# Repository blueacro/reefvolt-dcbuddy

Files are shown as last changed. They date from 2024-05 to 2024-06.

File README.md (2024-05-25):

# blueAcro ReefVolt DCBuddy

> Tired of AC bricks? Try the DCBuddy!

Various DC power accessories for the aquarium market

## DCBuddy

An Open Hardware design for 12-36V aquarium accessories, featuring:

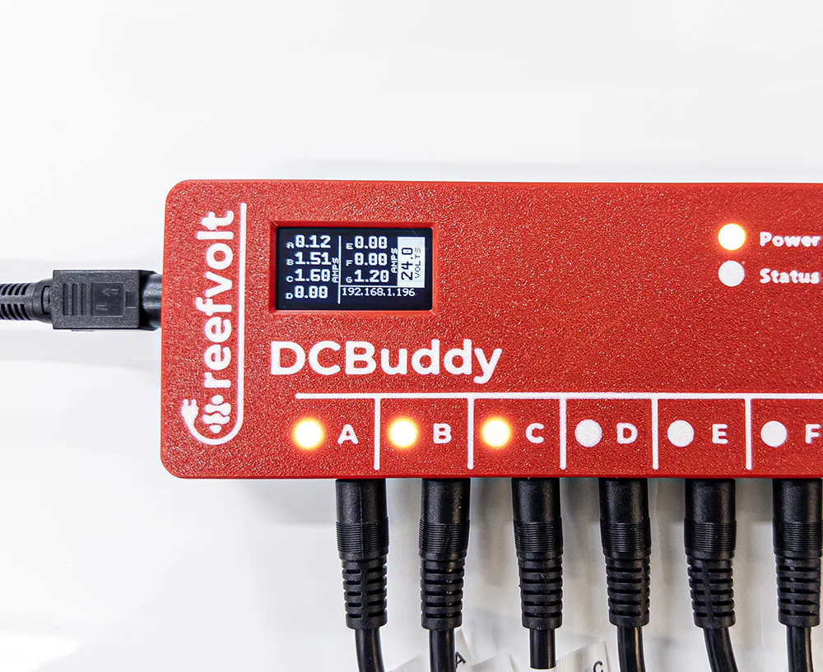
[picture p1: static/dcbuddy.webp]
Finished hardward

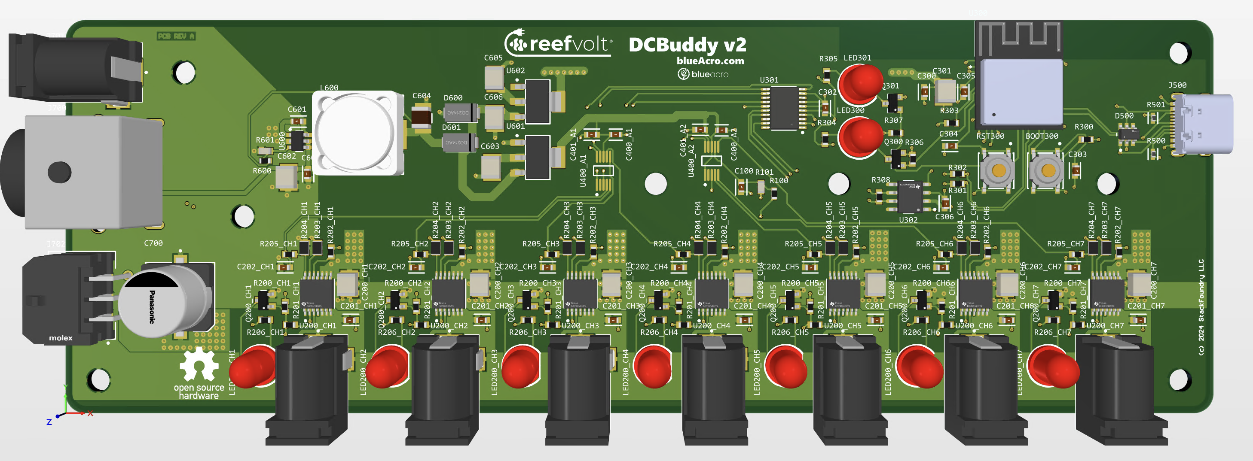
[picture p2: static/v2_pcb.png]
PCB screenshot


1. 7x, up to 5A (3A sustained), switched and current monitored power
   outlets with short circuit protection.
2. Works on an input range of 12-36V, up to 10A total current.
3. ESP32 on board, with USB-C port, for integration in Home Assistant.
4. Multiple input connectors including 2.1x5.5mm jack, DIN-4 jack, and
   Micro-Fit 3.0 jack with CAN bus support for power modules

## Buy

This product is available to purchase on https://blueacro.com

## Docs

More documentation is available on https://reefvolt.com/

## Firmware Install (Recovery, USB-C)

Need to reinstall the latest firmware? Visit
https://blueacro.github.io/reefvolt-dcbuddy/ with a Chrome-based
browser, plug in the DCBuddy over USB, and click Connect.

### Design Thread

This project was started on Reef2Reef. See the thread:

https://www.reef2reef.com/threads/tired-of-ac-bricks-try-the-dcbuddy.1009642/

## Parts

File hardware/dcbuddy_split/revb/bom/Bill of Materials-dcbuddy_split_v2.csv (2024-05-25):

Comment | Description | Designator | Footprint | LibRef | Quantity
PTS526SK15SMTR2LFS | Switch Tactile N.O. SPST Round Button Gull Wing 0.05A 12VDC 200000Cycles 2.45N SMD T/R | BOOT300, RST300, USR300 | FP-PTS526SK15SMTR2LFS-MFG | CMP-011-00015-1 | 3
CAP 1uF 10V X7R 0603 | Cap Ceramic 1uF 10V X7R 10% SMD 0603 125C Paper T/R | C100, C302, C304 | FP-CL10-IPC_B | CMP-001-00085-7 | 3
CAP 4.7uF 50V X7R 1210 | CAP CER 4.7UF 50V X7R 1210 | C200_A, C200_B, C200_C, C200_D, C200_E, C200_F, C200_G, C301, C605, C606 | CAPC3225X20N | CMP-001-00083-3 | 10
CAP 0.1uF 50V X7R 0603 | Cap Ceramic 0.1uF 50V X7R 20% SMD 0603 125C Paper T/R | C201_A, C201_B, C201_C, C201_D, C201_E, C201_F, C201_G, C202_A, C202_B, C202_C, C202_D, C202_E, C202_F, C202_G, C300, C303, C305, C306, C307, C401_X, C401_Y, C611 | FP-CL10-IPC_B | CMP-001-00084-7 | 22
CAP 4.7uF 0603 6.3V X7R | Cap Ceramic 4.7uF 6.3V X7R 10% SMD 0603 125°C Paper T/R | C400_X, C400_Y, C603, C613, C614 | FP-CL10-IPC_C | CMP-001-00101-4 | 5
CAP 2.2uF 0603 16V X6S | Cap Ceramic 2.2uF 16V X6S 10% Pad SMD 0603 105°C Low ESR T/R | C600 | FP-C1608-080-0_1-IPC_A | CMP-001-00117-2 | 1
CAP 0.47uF 50V 0603 | Multilayer Ceramic Capacitor, 0.47 uF, 50 V, ± 10%, X7R, 0603 [1608 Metric] | C601 | FP-C1608-080-0_1-IPC_A | CMP-001-00116-2 | 1
CAP 0.47uF 1210 50V X7R | Multilayer Ceramic Capacitor, 0.47 uF, 50 V, ± 10%, X7R, 1210 [3225 Metric] | C602, C609 | CAPC1210(3225)230_M | CMP-001-00128-1 | 2
CAP 10uF 1210 63V X7R | Multilayer Ceramic Capacitors MLCC - SMD/SMT 1210 10uF 63volts *Derate Voltage/Temp | C604, C610 | FP-GRM32E-0_2-0_3-MFG | CMP-001-00119-1 | 2
CAP 22uF 25V 1210 X7R | 1210 22 uF 25 V ±20% Tolerance X7R Multilayer Ceramic Chip Capacitor | C607 | FP-1210-L_3_2_0_3-W_2_5_0-MFG | CMP-001-00125-1 | 1
CAP 120uF 35V Poly 10mm | Cap Aluminum Polymer 120uF 35VDC 20%( 10 X 12.6mm) SMD 0.018 Ohm 4400mA 5000h 105C T/R | C608 | FP-OS-CON-SMT-F12-MFG | CMP-001-00127-1 | 1
C0603C560J5GACTU | Multilayer Ceramic Capacitor, 56 pF, 50 V, ± 5%, C0G (NP0), 0603 [1608 Metric] | C612 | FP-C0603C-CF-IPC_B | CMP-001-00126-1 | 1
CAP 56uF 63V Poly 10mm | Cap Aluminum 56uF 63V 20% (10 X 10.2mm) SMD 0.03 Ohm 1800mA 5000h 105 C Embossed T/R | C700 | FP-FKG-MFG | CMP-001-00124-1 | 1
USBLC6-4SC6 | ESD Suppressor 15KV 6-Pin SOT-23 T/R - Product that comes on tape, but is not reeled | D500 | FP-SOT23-6L-MFG | CMP-004-00040-1 | 1
SS14 |  | D600, D601 | SMA | CMP-080-0002-2 | 2
OLED_1_3_CARRIERBOARD | Use 4 pin header 0901471104 on board | DISP800 | OLED_1_3_CARRIERBOARD-Footprint-1 | CMP-00028-00008-2 | 1
PJ-0XX | 2.0 x 6.5 mm, 2.5 A, Horizontal, Through Hole, Dc Power Jack Connector | J200_A, J200_B, J200_C, J200_D, J200_E, J200_F, J200_G, J701 | CUI-PJ-002A_V | CMP-167-0003-2 | 8
M50-3630342R | 3 Pos. Male SIL Vertical SMT Conn. RoHS Compliant: Yes | J300, J600 | FP-M50-3630342R-MFG | CMP-002-00105-2 | 2
10155435-00011LF | 16 Position 5 A USB Right Angle Receptacle Connector | J500 | AMPHENOL_10155435-00011LF | CMP-243-000000-3 | 1
DIN4PWR |  | J700 | PD40S | CMP-167-0005-1 | 1
43045-1001 | Connector Wire to Board Header 10 Position 3 mm Solder Right Angle Thru-Hole Micro-Fit 3.0™ | J702 | FP-43045-1001-MFG | CMP-002-00106-1 | 1
IHLP5050FDER100M01 | Inductor Power Shielded Wirewound 10uH 20% 100KHz Powdered Iron 10A 17.2mOhm DCR 5050 T/R | L600 | FP-IHLP-5050FD-FP_2_945x4-MFG | CMP-006-00033-1 | 1
SRN4018-4R7M | Ind Power Semi-Shielded Wirewound 4.7uH 20% 100KHz Ferrite 1.9A 1515 T/R | L601 | FP-SRN4018-MFG | CMP-006-00036-2 | 1
LED_INDICATOR |  | LED200_A, LED200_B, LED200_C, LED200_D, LED200_E, LED200_F, LED200_G, LED300, LED301 | LED5MM | CMP-130-0003-6 | 9
NFET |  | Q200_A, Q200_B, Q200_C, Q200_D, Q200_E, Q200_F, Q200_G, Q300, Q301 | SOT23-3 | CMP-094-0000-1 | 9
100k 0603 1% | SMD Chip Resistor, 100 kOhm, ± 1%, 100 mW, 0603 [1608 Metric], Thick Film, General Purpose, Res Thick Film 1.6 x 0.8 mm 100K Ohm 1% 0.1W(1/10W) 100ppm/ C Molded SMD Paper T/R | R100, R600, R604 | RESC1608-IPC-LL | CMP-009-00222-1, CMP-009-00203-1 | 3
12k 0603 1% | SMD Chip Resistor, 12 kOhm, ± 1%, 100 mW, 0603 [1608 Metric], Thick Film, General Purpose | R101 | RESC1608X55X25LL10T15 | CMP-009-00236-1 | 1
10K 0603 1% | Res General Purpose Thick Film 0603 10K Ohm 1% 1/10W ±100ppm/°C Molded SMD Paper T/R | R200_A, R200_B, R200_C, R200_D, R200_E, R200_F, R200_G, R300, R301, R302, R303, R306, R307, R310 | RESC1608-IPC-ML | CMP-009-00191-4 | 14
4.7k 0603 1% | RES SMD 4.7K OHM 1% 1/10W 0603 | R201_A, R201_B, R201_C, R201_D, R201_E, R201_F, R201_G, R202_A, R202_B, R202_C, R202_D, R202_E, R202_F, R202_G, R205_A, R205_B, R205_C, R205_D, R205_E, R205_F, R205_G | RESC1608-IPC-ML | CMP-009-00205-1 | 21
RC0805FR-07470RL | SMD Chip Resistor, 470 Ohm, ± 1%, 125 mW, 0805 [2012 Metric], Thick Film, General Purpose | R203_A, R203_B, R203_C, R203_D, R203_E, R203_F, R203_G, R204_A, R204_B, R204_C, R204_D, R204_E, R204_F, R204_G | RESC2013X60X35LL10T20 | CMP-009-00233-1 | 14
220R 0603 5% | YAGEO - RC0603JR-07220RL - SMD Chip Resistor, 0603 [1608 Metric], 220 ohm, RC Series, 75 V, Thick Film, 100 mW | R206_A, R206_B, R206_C, R206_D, R206_E, R206_F, R206_G, R304, R305 | RESC1608-IPC-ML | CMP-009-00183-3 | 9
120R 1210 5% | SMD Chip Resistor, 120 Ohm, ± 5%, 500 mW, 1210 [3225 Metric], Thick Film, General Purpose | R308 | RESC3225X70X50LL20T20 | CMP-009-00240-1 | 1
AC0402FR-075K1L | SMD Chip Resistor, 5.1 kOhm, ± 1%, 63 mW, 0402 [1005 Metric], Thick Film, General Purpose | R500, R501 | FP-AC0402-IPC_A | CMP-009-00234-1 | 2
97.6k 0603 1% | Res Thick Film 0603 97.6K Ohm 1% 1/10W ±100ppm/°C Molded SMD Paper T/R | R602 | RESC1608-IPC-LL | CMP-009-00223-1 | 1
9.09k 0603 1% | SMD Chip Resistor, 9.09 kOhm, ± 1%, 100 mW, 0603 [1608 Metric], Thick Film, General Purpose | R603 | RESC1608-IPC-LL | CMP-009-00221-1 | 1
22.1k 0603 0.1% | RES SMD 22.1KOHM 0.1% 1/10W 0603 | R605 | RESC1608-IPC-LL | CMP-009-00207-3 | 1
4.32k 0603 1% | SMD Chip Resistor, 4.32 kOhm, ± 1%, 100 mW, 0603 [1608 Metric], Thick Film, Precision | R606 | RESC1608X55X30LL15T15 | CMP-009-00239-1 | 1
TPS1H100BQPWPRQ1 | Current Limit SW 1-IN 1-OUT 5V to 40V 4A Automotive 14-Pin HTSSOP EP T/R | U200_A, U200_B, U200_C, U200_D, U200_E, U200_F, U200_G | FP-PWP0014C-IPC_C | CMP-024-00009-1 | 7
ESP32-C3-MINI-1-N4 | Bluetooth, WiFi 802.11b/g/n, Bluetooth v5.0 Transceiver Module 2.412GHz ~ 2.484GHz PCB Trace Surface Mount | U300 | XCVR_ESP32-C3-MINI-1-N4 | CMP-206-000000-1 | 1
PCA9554APW | I2C/SMBus Interface 100kHz/400kHz 5.5V 16-Pin TSSOP Tube / IC I/O EXPANDER I2C 8B 16TSSOP | U301 | PW0016A_L | CMP-015-00016-1 | 1
TCAN1044VDRQ1 | R-PDSO-G8 TCAN1044 Tape & Reel (TR) CAN interface transceiver 100mV 4.905mm 5Mbps -40C~125C TA | U302 | FP-D0008A-IPC_B | CMP-015-00017-1 | 1
ADS1115IDGSR | 4-Channel Single ADC Delta-Sigma 860sps 16-bit Serial 10-Pin VSSOP T/R | U400_X, U400_Y | FP-DGS0010A-MFG | CMP-015-00014-1 | 2
LM76005RNPR | 3.5-V to 60-V, 5-A synchronous step-down voltage converter 30-WQFN -40 to 125 | U600 | FP-RNP0030A-MFG | CMP-019-00072-2 | 1
TPS70950DBVT | IC REG LINEAR 5V 150MA SOT23-5 / 150-mA, 30-V, UltraLow IQ, Low-Dropout Regulators with Enable | U601, U603 | FP-DBV0005A-IPC_B | CMP-019-00083-1 | 2
TPS54202DDCR | 4.5V to 28V Input, 2A Output, EMI Friendly Synchronous Step-Down Converter 6-SOT-23-THIN -40 to 125 | U602 | FP-DDC0006A-IPC_C | CMP-019-00081-1 | 1

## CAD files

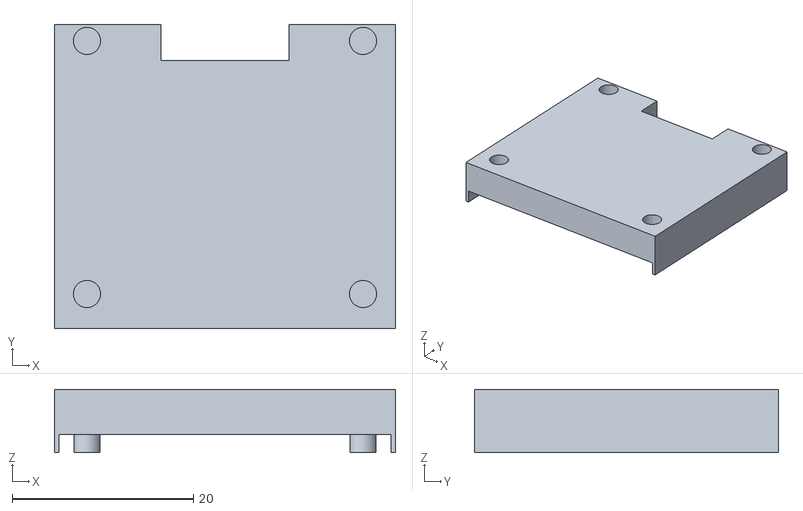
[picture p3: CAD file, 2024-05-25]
hardware/dcbuddy/case/reva/OledCarrier.stl
37.7 x 33.6 x 7.00

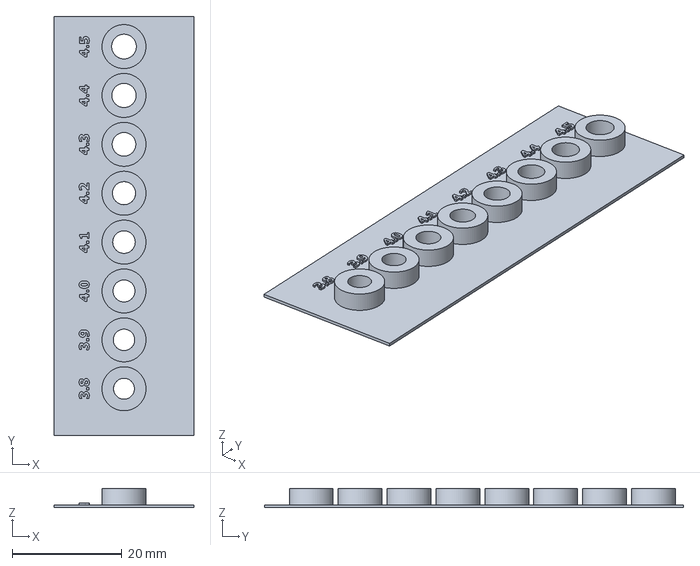
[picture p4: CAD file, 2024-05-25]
hardware/dcbuddy/case/reva/PCB/test plate press insert.3mf
25.4 x 76.2 x 3.50 mm

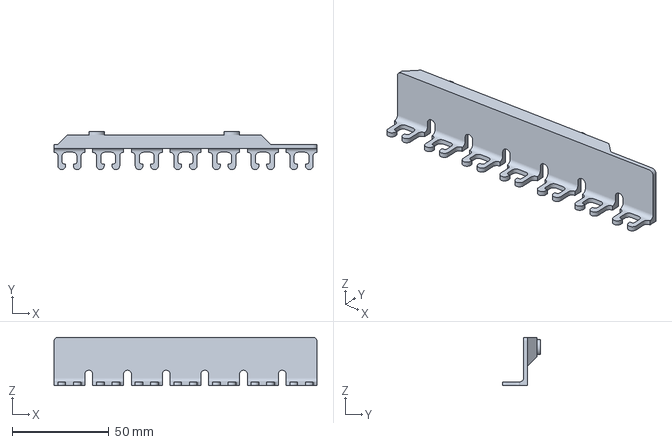
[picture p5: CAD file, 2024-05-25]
hardware/dcbuddy/case/reva/PCB/DCB2_CableClip.3mf
136.0 x 19.8 x 25.0 mm

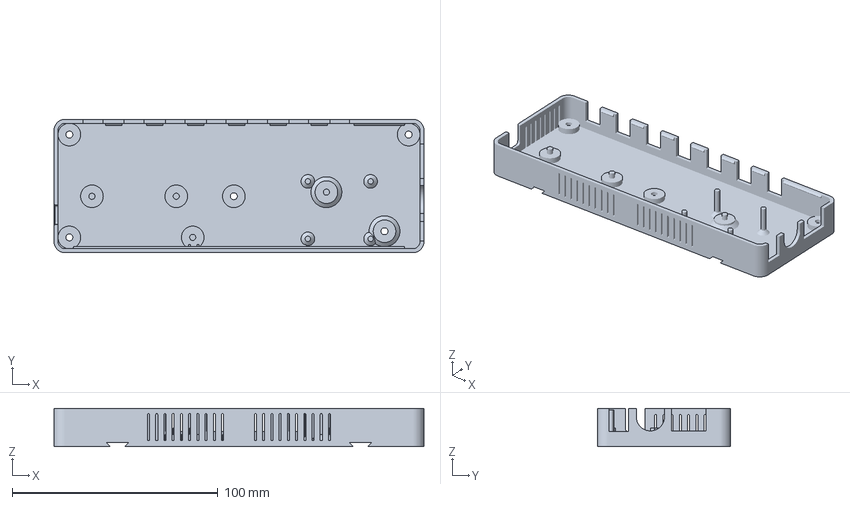
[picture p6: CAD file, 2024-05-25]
hardware/dcbuddy/case/reva/PCB/DCB2_BottomShell.3mf
179.9 x 64.9 x 18.6 mm

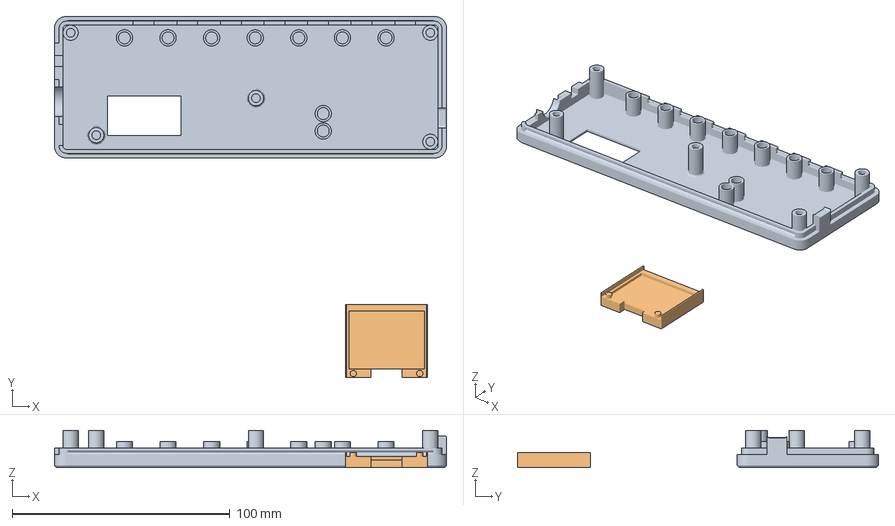
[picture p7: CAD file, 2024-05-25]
hardware/dcbuddy/case/reva/PCB/DCB2_TopShell.3mf
179.9 x 165.6 x 17.1 mm
DCB2_TopShell.stl
OledCarrier.stl

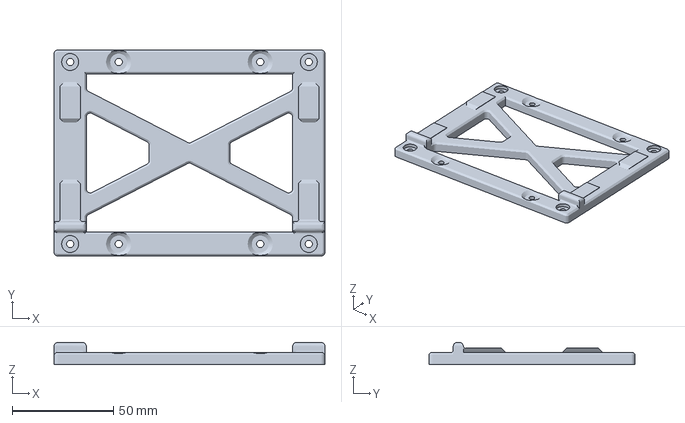
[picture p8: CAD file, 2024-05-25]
hardware/dcbuddy/case/reva/PCB/DCB2_Flange.3mf
134.0 x 102.0 x 11.0 mm

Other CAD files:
hardware/dcbuddy/case/reva/901471104.ipt
hardware/dcbuddy/case/reva/OLED_With_Carrier.iam
hardware/dcbuddy/case/reva/OledCarrier.ipt
hardware/dcbuddy/case/reva/PCB/ConvertedComponents/AMPHENOL_10155435-00011LF_CMP-243-000000-3.ipt
hardware/dcbuddy/case/reva/PCB/ConvertedComponents/CAPC3225X20N_CMP-001-00083-3.ipt
hardware/dcbuddy/case/reva/PCB/ConvertedComponents/CUI-PJ-002A_V_CMP-167-0003-2.ipt
hardware/dcbuddy/case/reva/PCB/ConvertedComponents/DCY0004A_M_CMP-019-00078-1.ipt
hardware/dcbuddy/case/reva/PCB/ConvertedComponents/DCY0004A_M_CMP-019-00080-1.ipt
hardware/dcbuddy/case/reva/PCB/ConvertedComponents/FP-1210-L_3_2_0_3-W_2_5_0-MFG_CMP-001-00125-1.ipt
hardware/dcbuddy/case/reva/PCB/ConvertedComponents/FP-43045-0601-MFG_CMP-002-00095-1.ipt
hardware/dcbuddy/case/reva/PCB/ConvertedComponents/FP-43045-0802-MFG_CMP-002-00102-1.ipt
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

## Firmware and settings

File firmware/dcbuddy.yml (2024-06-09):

esphome:
  name: dcbuddy
  comment: "Aquarium port controller"
  project:
    name: reefvolt.dcbuddy
    version: "v2"
  name_add_mac_suffix: true
  platformio_options:
    board_build.flash_mode: dio
  friendly_name: DCBuddy
  on_boot:
    priority: 600
    then:
      - output.turn_on: power_led

dashboard_import:
  package_import_url: github://blueacro/reefvolt-dcbuddy/firmware/dcbuddy.yaml@main
  import_full_config: false # or true

network:
    enable_ipv6: true

esp32:
  board: esp32-c3-devkitm-1
  framework:
    type: arduino

# Enable logging
logger:
  logs:
    component: ERROR # Suppress warning logs from the display drawing for too long

# Enable Home Assistant API
api:
  reboot_timeout: 0s # Prevent rebooting if no HA is connected
  services:
    - service: reset_ocp # Service to reset all OCP states
      then:
        - lambda: |-
            id(power_resets_port)[0] = 0;
            id(power_resets_port)[1] = 0;
            id(power_resets_port)[2] = 0;
            id(power_resets_port)[3] = 0;
            id(power_resets_port)[4] = 0;
            id(power_resets_port)[5] = 0;
            id(power_resets_port)[6] = 0;

ota:

wifi:
  # Enable fallback hotspot (captive portal) in case wifi connection fails
  ap:
    ssid: "DCBuddy Fallback Hotspot"
    password: "password"

prometheus:

web_server:
  port: 80
  log: False
  version: 3

improv_serial:

captive_portal:

status_led:
  pin: GPIO3

font:
    - file: 'five.ttf'
      id: five
      size: 8
    - file: "refsan.ttf"
      id: refsan
      size: 9
    - file: "PixelGameFont.ttf"
      id: bigfont
      size: 14


display:
  - platform: ssd1306_i2c
    model: "SH1106 128x64"
    #address: 0x78
    update_interval: 1s
    lambda: |-

     int offset = 0;
     it.printf(0, 3+offset, id(five), "A");
     it.printf(8, offset, id(bigfont), "%1.2f", fabs(id(amps_A).state));

     it.printf(55, 3+offset, id(five), "E");
     it.printf(55+8, offset, id(bigfont), "%1.2f", fabs(id(amps_E).state));

     offset += 16;

     it.printf(0, 3+offset, id(five), "B");
     it.printf(8, offset, id(bigfont), "%1.2f", fabs(id(amps_B).state));

     it.printf(55, 3+offset, id(five), "F");
     it.printf(55+8, offset, id(bigfont), "%1.2f", fabs(id(amps_F).state));

     offset += 16;

     it.printf(0, 3+offset, id(five), "C");
     it.printf(8, offset, id(bigfont), "%1.2f", fabs(id(amps_C).state));

     it.printf(55, 3+offset, id(five), "G");
     it.printf(55+8, offset, id(bigfont), "%1.2f", fabs(id(amps_G).state));


     offset += 16;

     it.printf(0, 3+offset, id(five), "D");
     it.printf(8, offset, id(bigfont), "%1.2f", fabs(id(amps_D).state));


     it.set_rotation(DISPLAY_ROTATION_270_DEGREES);
     it.printf(20, 38, id(five), "AMPS");
     it.printf(30, 38+55, id(five), "AMPS");
     it.line(0,48,63,48);
     it.line(16,48+55,63,48+55);
     it.line(16,48,16,127);

     it.filled_rectangle(16,48+55,63,127);

     it.printf(23, 48+55+3, id(bigfont), COLOR_OFF, "%2.1f", id(volts_in).state);
     it.printf(25, 48+55+2+10, id(five), COLOR_OFF, "VOLTS");

     it.set_rotation(DISPLAY_ROTATION_0_DEGREES);


     it.printf(50, 46, id(refsan), "%s", id(ip1).state.c_str());

canbus:
  - platform: esp32_can
    tx_pin: GPIO0
    rx_pin: GPIO1
    bit_rate: 125kbps
    can_id: 4
    on_frame:
    - can_id: 500
      use_extended_id: false
      then:
      - lambda: |-
          std::string b(x.begin(), x.end());
          ESP_LOGI("can id 500", "%s", &b[0] );


globals:
  - id: power_resets_port
    type: int[7]
  - id: max_reset_port
    type: int
    initial_value: "10"


# Core port logic - one per port assignment to the sensor and the output state,
# as well as internal and external HomeAssistant switch object wiring

packages:
  port_a: !include
    file: 'packages/dcbuddy_port.yaml'
    vars:
      port: A
      port_id: 0
      ads1115_id: ads1115_1
      ads1115_multiplexer: 'A0_GND'
  port_b: !include
    file: 'packages/dcbuddy_port.yaml'
    vars:
      port: B
      port_id: 1
      ads1115_id: ads1115_1
      ads1115_multiplexer: 'A1_GND'
  port_c: !include
    file: 'packages/dcbuddy_port.yaml'
    vars:
      port: C
      port_id: 2
      ads1115_id: ads1115_1
      ads1115_multiplexer: 'A2_GND'
  port_d: !include
    file: 'packages/dcbuddy_port.yaml'
    vars:
      port: D
      port_id: 3
      ads1115_id: ads1115_1
      ads1115_multiplexer: 'A3_GND'
  port_e: !include
    file: 'packages/dcbuddy_port.yaml'
    vars:
      port: E
      port_id: 4
      ads1115_id: ads1115_2
      ads1115_multiplexer: 'A0_GND'
  port_f: !include
    file: 'packages/dcbuddy_port.yaml'
    vars:
      port: F
      port_id: 5
      ads1115_id: ads1115_2
      ads1115_multiplexer: 'A1_GND'
  port_g: !include
    file: 'packages/dcbuddy_port.yaml'
    vars:
      port: G
      port_id: 6
      ads1115_id: ads1115_2
      ads1115_multiplexer: 'A2_GND'
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

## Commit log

2024-05-25 Initial Update license
    [901471104.ipt, AMPHENOL_10155435-00011LF_CMP-243-000000-3.ipt, Bill of Materials-dcbuddy_split_v2.csv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]
2024-05-27 Add serial-improv buttons
2024-06-04 Add indirect port switch with OCP protection (#1)
    * Add indirect port switch with OCP protection
    Also paves the way for voltage limits.
    * Reduce boilerplate by using package includes
    * Remove the port id map, pass in switch objects directly
2024-06-04 ESPHome doesn't do Jinja filters (#2)
    ${thing | filter} doesn't actually exist, though its not an
    error. Curious.
    Make all the names upper case
    [dcbuddy.yml]
2024-06-05 Support versions, IPv6, mac-suffix name (#3)
    * Support versions, IPv6, mac-suffix name
    Reports versions in the firmware
    Stamps the firmware with a build
    Turns on ipv6
    Turns on mac suffix name
    * Check version tagging
    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
2024-06-05 Report OCP violation counts and a service to reset it (#5)
    [dcbuddy.yml]
2024-06-06 Overvoltage and undervoltage support (#6)
    * Overvoltage and undervoltage support
    Refactored the initial monolithic script into just being a semaphore
    script
    Implement UVLO/OVLO on a per-port basis
    * Don't use a slider, use a box
    * Fix the semaphore to be a polled semaphore
    [dcbuddy.yml]
2024-06-09 Enable prometheus endpoint (#8)
    * Enable prometheus endpoint
    * Swap to v3 server
    [dcbuddy.yml]
